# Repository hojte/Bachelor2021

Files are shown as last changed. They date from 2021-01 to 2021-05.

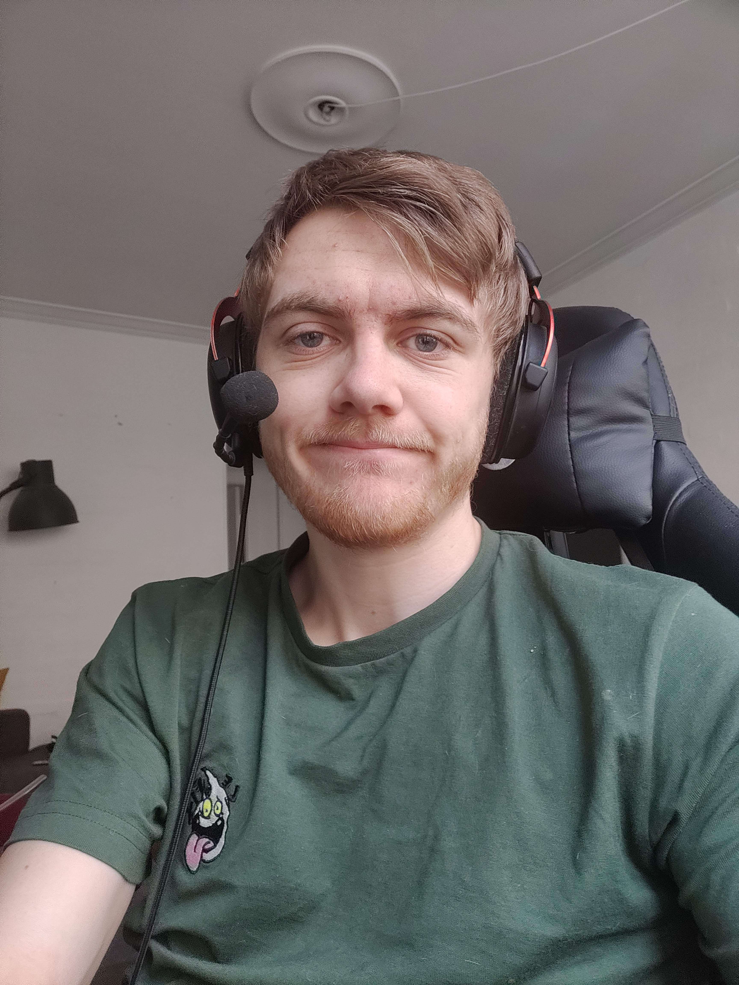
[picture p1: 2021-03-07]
itu_vid_it/assets/testImgMathias.jpg

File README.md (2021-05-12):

# Bachelor 2021
## Purpose
To Track and follow objects with an iOS or Android phone.

## Components
- Flutter with Tensorflow
- Arduino microcontroller
- Steppermotor actuator

## Contributors
- Mathias Højte Olsen, Frderik Mads Pil & Mathias Dashtbani Mikkelsen
- Supervised by: Andres Faina. Co-supervisor: Fabricio Narcizo

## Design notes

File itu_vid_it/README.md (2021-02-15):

# ituvidit

Bachelor project 

## Getting Started

This project is a starting point for a Flutter application.

A few resources to get you started if this is your first Flutter project:

- [Lab: Write your first Flutter app](https://flutter.dev/docs/get-started/codelab)
- [Cookbook: Useful Flutter samples](https://flutter.dev/docs/cookbook)

For help getting started with Flutter, view our
[online documentation](https://flutter.dev/docs), which offers tutorials,
samples, guidance on mobile development, and a full API reference.

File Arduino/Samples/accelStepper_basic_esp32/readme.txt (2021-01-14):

Controls a steppermotor via. the ESP32
Code for quarter step mode and eight step mode.
Code for the AccelLibrary

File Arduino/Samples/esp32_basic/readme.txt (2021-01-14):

- Basic example for the ESP32
- StepPin => D2, DirPin => D4
- Rotates 200 steps clockwise and prints "Clockwise" to serial bus if any. Then rotates 200 steps counterclockwise. ETC....
- Rotates as fast as possible (delay on 500 microSeconds between steps) shorter delay blocks motor....

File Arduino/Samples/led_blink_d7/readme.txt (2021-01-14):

- Blink an LED connected to D7 (GPIO13) on the NodeMCU
- Use a resistor between LED and D7...idk why

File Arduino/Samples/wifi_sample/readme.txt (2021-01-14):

-  Basic WiFi sample for NodeMCU. Log into my network and prints out the retrieved IP. And then just blinks.

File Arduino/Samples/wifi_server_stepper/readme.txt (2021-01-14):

- Sample from the tut on https://www.engineersgarage.com/esp8266/nodemcu-esp8266-stepper-motor-interfacing/
- For the NodeMCU. Step=> D3, Dir=> D4.
- Creates a server, prints out the IP to serial. 
- From the webpage of the IP, the motor can be controlled.

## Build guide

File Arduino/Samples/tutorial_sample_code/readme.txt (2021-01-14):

- code from https://howtomechatronics.com/tutorials/arduino/how-to-control-stepper-motor-with-a4988-driver-and-arduino/
- Rotates one rev clockwise then two revs counter clockwise
- StepPin -> D3, dir -> D4, NodeMCU!
- Altered to printOut as well as turn build in LED on and off when shifting between clocks.

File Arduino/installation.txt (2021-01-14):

Arduino (NodeMCU v0.9 w/ ESP8266 module):
https://randomnerdtutorials.com/how-to-install-esp8266-board-arduino-ide/  
Tools -> Serial monitor -> 115200 baudrate. (for print-outs-debugging)
espcomm_open failed -> USB ud og ind igen.

ESP32:
add https://dl.espressif.com/dl/package_esp32_index.json to boards manager.
Tools -> Board -> ESP32 Dev Module

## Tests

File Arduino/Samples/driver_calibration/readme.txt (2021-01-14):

- Code for calibrating the max current of the driver. Holds the step pin high such that the board uses constant current, to make calibration easier. 
- Adjust the potentiometer st. the current (Ampere) does not exeed 350mA for NEMA 17 in full step mode.
- The more resistance of the motor rotating axis, the more current used.

- Made for the NodeMCU, with StepPin -> D3, and DirPin -> D4

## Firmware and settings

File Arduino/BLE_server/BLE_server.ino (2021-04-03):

/*
    Based on Neil Kolban example for IDF: https://github.com/nkolban/esp32-snippets/blob/master/cpp_utils/tests/BLE%20Tests/SampleServer.cpp
    Ported to Arduino ESP32 by Evandro Copercini
    updates by chegewara

    Modified by VidIt to suit our needs.
*/

#include <BLEDevice.h>
#include <BLEUtils.h>
#include <BLEServer.h>
#include <AccelStepper.h>


#define SERVICE_UUID        "ea411899-d14c-45d5-81f0-ce96b217c64a"
#define CHARACTERISTIC_UUID "91235981-23ee-4bca-b7b2-2aec7d075438"
#define CHARACTERISTIC_UUID_RX "52e6a8f9-5688-4d81-b1ad-ece87b095e52"

const int ledPin = 2;
BLEServer *VidItServer;
BLEService *VidItService;
BLECharacteristic *VidItCharacteristic;
BLEAdvertising *VidItAdvertising;

// defines pins numbers
// 1st motor
const int stepPin_1 = 33; 
const int dirPin_1 = 32; 
const int MS1_1 = 27; 
const int MS2_1 = 26; 
const int MS3_1 = 25; 

// 2nd motor
const int stepPin_2 = 22; 
const int dirPin_2 = 23;
const int MS1_2 = 18; 
const int MS2_2 = 19; 
const int MS3_2 = 21; 

// Define motor interface type
#define motorInterfaceType 1

// Creates an instance accelstepper
AccelStepper stepper1(motorInterfaceType, stepPin_1, dirPin_1);
AccelStepper stepper2(motorInterfaceType, stepPin_2, dirPin_2);




void setup() {
  Serial.begin(115200);
  Serial.println("STARTING BLE FOR VIDIT");
  pinMode(ledPin, OUTPUT);

  //Init the BLE device with the name.
  BLEDevice::init("VidItESP32");
  //Creating the BLE device as a BLE server
  VidItServer = BLEDevice::createServer();

  
  //Creating BLE service with the service UUID
  VidItService = VidItServer->createService(SERVICE_UUID);
  //Creating BLE characteristic with UUID wit properties read and write.
  VidItCharacteristic = VidItService->createCharacteristic(
                                         CHARACTERISTIC_UUID,
                                         BLECharacteristic::PROPERTY_READ |
                                         BLECharacteristic::PROPERTY_WRITE
                                       );
                                       
  //The setValue should be changed in the future to display the state
  VidItCharacteristic->setValue("startVal");
  VidItService->start();
  //The following sets the attributes for the advertising. Such as the UUID, the scan response and start 
  //the BLE adverstising so BT devices can find it. 
  VidItAdvertising = BLEDevice::getAdvertising();
  VidItAdvertising->addServiceUUID(SERVICE_UUID);
  VidItAdvertising->setScanResponse(true);
  VidItAdvertising->setMinPreferred(0x06);  // functions that help with iPhone connections issue
  VidItAdvertising->setMinPreferred(0x12);
  BLEDevice::startAdvertising();
  
  Serial.println("READY TO BE PAIRED");
  
  pinMode(MS3_1,OUTPUT);
  pinMode(MS2_1,OUTPUT);
  pinMode(MS1_1,OUTPUT);
  digitalWrite(MS3_1,HIGH);
  digitalWrite(MS2_1,HIGH);
  digitalWrite(MS1_1,HIGH);

  pinMode(MS3_2,OUTPUT);
  pinMode(MS2_2,OUTPUT);
  pinMode(MS1_2,OUTPUT);
  digitalWrite(MS3_2,HIGH);
  digitalWrite(MS2_2,HIGH);
  digitalWrite(MS1_2,HIGH);  
}

int connectedUsers = 0;

void loop() {
  stepper1.setMaxSpeed(10000.0); 
  stepper2.setMaxSpeed(10000.0); 
  
  connectedUsers = VidItServer->getConnectedCount();
  
  if(connectedUsers > 0){
    digitalWrite(ledPin, HIGH);
    //Serial.println(VidItCharacteristic->getValue().c_str());
    
    //Splitting the input string into direction and speed
    std::string inputFromAPP = VidItCharacteristic->getValue().c_str();
    std::string delimiter = ":"; 
    std::string _direction = inputFromAPP.substr(0,inputFromAPP.find(delimiter));

    //Removes the direction from the string and finds the xspeed
    inputFromAPP.erase(0, inputFromAPP.find(delimiter) + delimiter.length());
    std::string xSpeed = inputFromAPP.substr(0,inputFromAPP.find(delimiter));
    double convertedXSpeed = atof(xSpeed.c_str()); 

    //Removes the direction from the string and finds the yspeed
    inputFromAPP.erase(0, inputFromAPP.find(delimiter) + delimiter.length());
    std::string ySpeed = inputFromAPP.substr(0,inputFromAPP.find(delimiter));
    double convertedYSpeed = atof(ySpeed.c_str()); 

    


    
    //Debug statement - printing in console.
    if (_direction== "R"){
      stepper1.setSpeed(-convertedXSpeed);
      stepper2.setSpeed(convertedYSpeed);
      }
      else if (_direction== "L"){
        stepper1.setSpeed(convertedXSpeed); 
        stepper2.setSpeed(convertedYSpeed);
        }
      else if(_direction== "U"){
        stepper1.setSpeed(convertedXSpeed); 
        stepper2.setSpeed(convertedYSpeed);
        }
      else if(_direction== "D"){
        stepper1.setSpeed(convertedXSpeed); 
        stepper2.setSpeed(-convertedYSpeed); 
        }
      else if(_direction== "U&R"){
        stepper1.setSpeed(-convertedXSpeed);
        stepper2.setSpeed(convertedYSpeed);
        }
      else if(_direction== "U&L"){
        stepper1.setSpeed(convertedXSpeed);
        stepper2.setSpeed(convertedYSpeed);
        }
      else if(_direction== "D&R"){
        stepper1.setSpeed(-convertedXSpeed);
        stepper2.setSpeed(-convertedYSpeed);
        }
      else if(_direction== "D&L"){
        stepper1.setSpeed(convertedXSpeed);
        stepper2.setSpeed(-convertedYSpeed);
        }
      else{
        stepper1.setSpeed(0.0);
        stepper2.setSpeed(0.0);
     } 
     stepper1.runSpeed();   
     stepper2.runSpeed();       
  }
  else{
    digitalWrite(ledPin, LOW);
    delay(2);
  }
}

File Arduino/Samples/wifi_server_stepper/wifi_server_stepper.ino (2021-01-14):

/*****************************************************
 * Date: 9 july 2018
 * Written by: Usman Ali Butt
 * Property off: microcontroller-project.com
 * ***************************************************/
#include <ESP8266WiFi.h>
 
const char* ssid = "Fibernet-IA01046616";
const char* password = "rfw2zZWn";

int Step = 0; //GPIO0---D3 of Nodemcu--Step of stepper motor driver
int Dir  = 2; //GPIO2---D4 of Nodemcu--Direction of stepper motor driver

WiFiServer server(80);
 
void setup() {
  Serial.begin(115200);
  delay(10);
 pinMode(Step, OUTPUT); //Step pin as output
 pinMode(Dir,  OUTPUT); //Direcction pin as output
 digitalWrite(Step, LOW); // Currently no stepper motor movement
 digitalWrite(Dir, LOW);  
 
  // Connect to WiFi network
  Serial.println();
  Serial.println();
  Serial.print("Connecting to ");
  Serial.println(ssid);
 
  WiFi.begin(ssid, password);
 
  while (WiFi.status() != WL_CONNECTED) {
    delay(500);
    Serial.print(".");
  }
  Serial.println("");
  Serial.println("WiFi connected");
 
  // Start the server
  server.begin();
  Serial.println("Server started");
 
  // Print the IP address on serial monitor
  Serial.print("Use this URL to connect: ");
  Serial.print("http://");    //URL IP to be typed in mobile/desktop browser
  Serial.print(WiFi.localIP());
  Serial.println("/");
 
}
 
void loop() {
  // Check if a client has connected
  WiFiClient client = server.available();
  if (!client) {
    return;
  }
 
  // Wait until the client sends some data
  Serial.println("new client");
  while(!client.available()){
    delay(1);
  }
 
  // Read the first line of the request
  String request = client.readStringUntil('\r');
  Serial.println(request);
  client.flush();
 
  // Match the request
  int i=0;
  int value = LOW;
  
  if (request.indexOf("/Command=forward") != -1)  { //Move 50 steps forward
    digitalWrite(Dir, HIGH); //Rotate stepper motor in clock wise direction
          for( i=1;i<=50;i++){
          digitalWrite(Step, HIGH);
          delay(1);
          digitalWrite(Step, LOW);
          delay(1);}
    value = HIGH;
  }
  
  if (request.indexOf("/Command=backward") != -1)  { //Move 50 steps backwards
    digitalWrite(Dir, LOW); //Rotate stepper motor in anti clock wise direction
          for( i=1;i<=50;i++){
          digitalWrite(Step, HIGH);
          delay(1);
          digitalWrite(Step, LOW);
          delay(1);}
    value = LOW;
  }

  // Return the response
  client.println("HTTP/1.1 200 OK");
  client.println("Content-Type: text/html");
  client.println(""); //  do not forget this one
  client.println("<!DOCTYPE HTML>");
  client.println("<html>");
  client.println("<h1 align=center>Stepper motor controlled over WiFi</h1><br><br>");
  client.print("Stepper motor moving= ");
 
  if(value == HIGH) {
    client.print("Forward");
  } else {
    client.print("Backward");
  }
  client.println("<br><br>");
  client.println("<a href=\"/Command=forward\"\"><button>Forward </button></a>");
  client.println("<a href=\"/Command=backward\"\"><button>Backward </button></a><br />");  
  client.println("</html>");
  delay(1);
  Serial.println("Client disonnected");
  Serial.println("");
 
}

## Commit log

2021-01-14 Arduino samples with readme's, update readme
2021-02-10 arduino sketches
    [CircuitV1.fzz, CircuitV2.fzz, CircuitV3.fzz]
2021-02-12 circuit v3
    [CircuitV3.fzz]
2021-02-12 new circuit layout
2021-02-12 more circuit
    [CircuitV3.fzz]
2021-02-22 added change between back and front camera
2021-02-24 update esp32 pin mapping for PCB
2021-02-24 update blueprint to match PCB
    [CircuitV3.fzz]
2021-02-28 bluetooth chain promises
2021-03-01 use correct characteristics and fix ble server
    [BLE_server.ino]
2021-03-01 fix ble server location
    [BLE_server.ino]
2021-03-01 Added record button, began on recording feature
2021-03-05 BLE_server now receives left and right data when button is taped
2021-03-07 x aksen virker i forhold til object der ikke fylder hele skærmen
2021-03-07 fix a bug where server does not recive data
    [BLE_server.ino]
2021-03-08 mess around with CameraController
2021-03-15 added print
2021-03-15 Bug fix - bnd box is now drawn in the abckground of the buttons
2021-03-15 change camFlip to useFrontCam use imagestream dimentions in ffmpeg command orientate images correctly for tracking model (dosen't support upside down modes) lower threshold a bit. move string parsing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
2021-03-15 fix framerate calculation
2021-03-15 rerender on each frame analysis complete
2021-03-16 reorganize imports camera
2021-03-17 remove record button from correct OS
2021-03-19 add native device rotation package
2021-03-19 refactored buttons
2021-03-19 fixed screen resolution. Tracking works on both horizontal and vertical. Tracking work on the front camera on vertical mode, however, landscape mode does not work.
2021-03-22 hot fix to camera direction rotation
    [BLE_server.ino]
2021-03-22 MountControls UI
2021-03-22 fred unsaved arduino
2021-03-24 Mount controls created on front page.
2021-03-24 Mount controls changed pause icon
2021-03-24 Parsing BLE to mountremotecontrol to senddata
2021-03-24 removed "compute.boundingBoxCenter;" from mountremotecontrol
2021-03-24 minimalistic flip and record buttons
2021-03-24 Fixed mountcontroller responding with wrong results
2021-03-24 make icon background use material fix overflowing text on smaller devices
2021-03-24 rename manual controller to what it is remove prints....
2021-03-26 gridView now has a switch
2021-03-27 removed prints
2021-03-27 update espDevice var on found from connected devices, force false isConnecting
2021-03-27 update ble icon base on write status from controller, not used in manual mountManualController.dart
2021-03-28 text on mount not found + controls align sections a bit better landscape needs work though
2021-03-30 tostring on coordinates, actually filterRecognitions still use the first match
2021-04-03 add delay if no device is connected set a startValue on the characteristic
2021-04-05 motors did not rotate correctly. Speed was set when it should not
2021-04-09 speedCalculation is now working as expected for both x and y axis
2021-04-09 mountManualController fixed buttons for orientation landscape
2021-04-09 link gridview -> camera -> mountController
2021-04-09 removed prints and debug stuff
2021-04-11 Added speed slider, speed display and change tracking data sent from MountManualController.
2021-04-12 Exiting mountcontrols stop moving
2021-04-12 stop motor if TrackingData() provided
2021-04-12 round down on framerate calc
2021-04-13 only zoom on initialised controller and mounted
2021-04-14 zoom func return if not mounted
2021-04-19 add MOT switch + lint
2021-04-19 use motEnabled switch
2021-04-30 non 0 initial speed manual mount
2021-05-12 move samples to sample dir
